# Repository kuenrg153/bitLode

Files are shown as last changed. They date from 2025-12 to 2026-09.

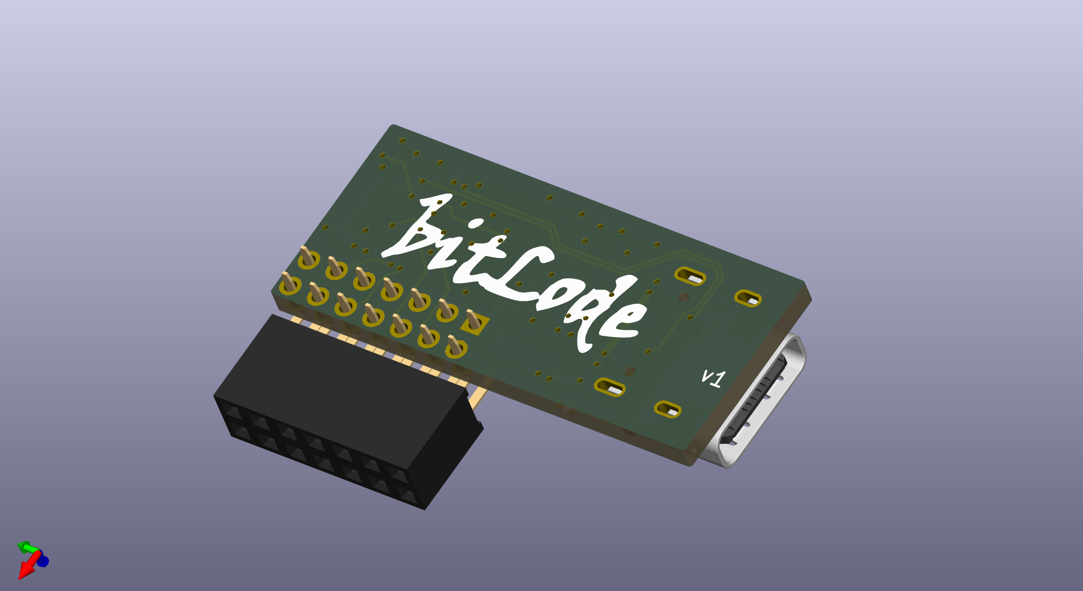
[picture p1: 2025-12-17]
doc/bitLodePCBA.png

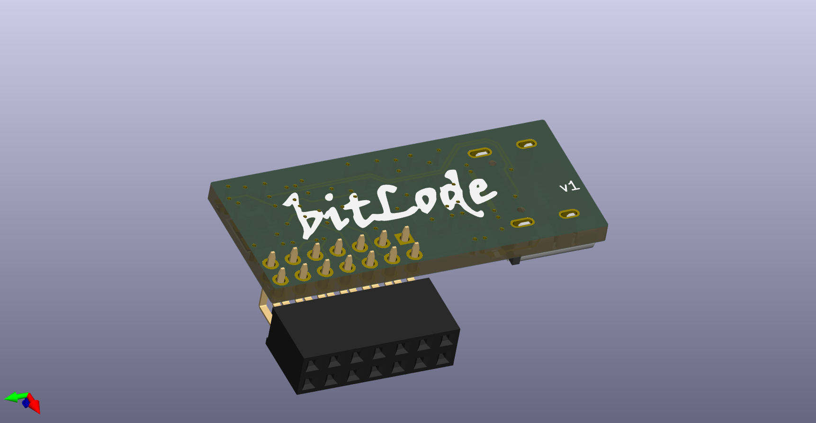
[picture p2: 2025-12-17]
bitLoadPCBA.png

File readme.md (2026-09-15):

## bitLode V2

bitLode

bitLode V2 is an RP2040 USB adapter that connects a PC, laptop or Raspberry Pi to a Whatsminer M30 (and similar)
hashboard. It exposes the hashboard's UART, reset and I2C over USB.

It's a fork of [aditBoard v2](https://github.com/skot/aditBoard/tree/v2) by Skot. It changes the
board for Whatsminer hashboards and adds firmware, host tools and an AI diagnostics skill.

| Path | Contents |
|---|---|
| `bitLodeV2.kicad_pro` / `.kicad_sch` / `.kicad_pcb` | KiCad 10 project: schematic and 6-layer PCB |
| `bitLodeV2.kicad_sym`, `bitLodeV2.pretty/`, `bitLodeV2.3dshapes/` | project-local symbols, footprints and 3D models |
| `Manufacturing Files/` | Gerbers, drill files, BOM and component placement for PCBA (e.g. [JLCPCB](https://jlcpcb.com)) |
| [`firmware/`](firmware/) | RP2040 firmware source (Rust/Embassy) with prebuilt `bin/bitlode-fw.elf` and `bin/bitlode-fw.uf2` |
| [`tools/`](tools/) | Python host tools: port discovery, system commands, hashboard init/replay, nonce verification, rig power |
| [`skills/`](skills/) | AI agent skill for diagnosing a Whatsminer M30S (KF1950) hashboard through the bitLode |

### Quick start

1. **Hardware** Send `Manufacturing Files/gerbers/`, the BOM and the placement file to your PCB assembler. Some notes: 

a) Fab houses might try to replace the cyrstal with an oscillator (learned this the hard way) - don't let them!

b) The LED is hard to source - but it works fine with out it!

c) Just do SMT at the fab house - solder the connector yourself and save a little bit. You can even try to sample the connector for free from Samtec - SQT-107-01-L-D-RA

d) Note that this version interferes with the fan in the original enclosure. If you're looking to use it long term in the enclosure you probably want to modify it (make the board into a bit of an upside down L and extend the header down) to clear the fan.

e) Currently I have NOT made the AntHat (https://github.com/skot/AntHat) equivalent for controlling the Whatsminer PSU and fans. Let me know if there is interest there.

bitLode_2sides

2. **Firmware** 
The firmware is based on https://github.com/256foundation/emberone-usbserial-fw with a few modifications around baud rates.

If you have trouble flashing it via the regular uf2 over boot loader then you can try using a Pi Pico running Debugprobe
https://www.electronics-lab.com/understanding-the-ways-to-debug-your-raspberry-pi-pico-development-board/

If you go this route then it's really handy to get an adapter ( https://www.aliexpress.com/item/1005009527726103.html ) to bring out the SWD lines.

To build it yourself, see [`firmware/README.md`](firmware/README.md).
   
3. **Plug in USB.** The board appears as `e3be:40e1` with two serial ports: control (interface 0) and ASIC UART (interface 2).
   ```sh
   pip install pyserial
   python3 tools/bitlode_sys.py ident   # -> ember-one kf1950 pio96 +sys-cmds 2026-09-15
   ```

### AI skill
The point of these skills is to help people learn how to communicate with, configure and diagnose Whatsminer M30 hashboards. 

I haven't yet done it but you could pair these skills up with Mujina (https://github.com/256foundation/mujina) and actually hash. Note that the RP2040 canNOT keep up with the 12Mbaud native baud rate required to fully hash but maybe someone can run with this project and figure that out.

`skills/bitlode-hashboard-diag/` is a [Claude Code skill](https://docs.claude.com/en/docs/claude-code/skills).
Link it into your skills directory, then run the agent from the repository root so its
relative paths (`tools/`, `sessions/`, `captures/`) resolve:

```sh
mkdir -p ~/.claude/skills
ln -s "$PWD/skills/bitlode-hashboard-diag" ~/.claude/skills/bitlode-hashboard-diag
```

Before its hashing test (T3), the skill needs:
- the job pool, generated once with `cd tools && python3 make_fresh_jobs.py 165000`
- the `whatsminer_private_api_py` package (its `wm_ssh.py`) for `tools/wm.sh`, pointed to by `WM_API_DIR`
- a known-good nonce capture for the verifier's control, pointed to by `KF_CONTROL_PKL`

### License

Firmware: GPL-3.0 (see `firmware/LICENSE`).

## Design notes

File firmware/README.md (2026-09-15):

# bitLode firmware

RP2040 firmware for the bitLode board. It turns one USB connection into two serial ports:
a **control port** (I2C, GPIO, ADC, LED, system commands) and a **data port** that passes
UART traffic straight through to the hashboard ASIC chain.

| | |
|---|---|
| USB VID:PID | `e3be:40e1` |
| Manufacturer / product | `256F` / `EmberOne00` |
| Serial number | murmur3 hash of the SPI flash's 64-bit unique ID (different on every board) |
| Identity string | `ember-one kf1950 pio96 +sys-cmds 2026-09-15` (control page `0x0F`, cmd `0x00`) |
| System clock | 96 MHz from the 12 MHz crystal, so the PIO UART divides exactly to 12 Mbaud |

Prebuilt images of this source are in [`bin/`](bin/): `bitlode-fw.elf` for SWD and `bitlode-fw.uf2` for the USB bootloader.

## Building

```sh
curl --proto '=https' --tlsv1.2 -sSf https://sh.rustup.rs | sh
rustup target add thumbv6m-none-eabi

cargo build --release --locked
# output: target/thumbv6m-none-eabi/release/firmware (ELF)
```

## Flashing

**SWD** (any debug probe, e.g. a Pico running Debugprobe, on SWCLK / SWDIO / GND):

```sh
openocd -f interface/cmsis-dap.cfg -f target/rp2040.cfg -c "adapter speed 1000" \
        -c "program bin/bitlode-fw.elf verify reset exit"
# or: cargo install probe-rs-tools --locked && cargo flash --release --chip RP2040
```

**USB bootloader.** If the board already runs this firmware, reboot it into the RP2040 ROM
bootloader with `tools/bitlode_sys.py bootsel`. On a blank board, hold BOOTSEL while plugging in USB.
Then copy `bin/bitlode-fw.uf2` onto the `RPI-RP2` drive.

## Pinout

| RP2040 pin | Function |
|---|---|
| GPIO8 / GPIO9 | ASIC UART TX / RX (PIO UART) |
| GPIO11 | `asic_resetn` (active low, idles high) |
| GPIO0 | `asic_pwr_en` (active high, idles low) |
| GPIO18 | `asic_io_pwr_en` (active high, idles low) |
| GPIO14 / GPIO15 | I2C SDA / SCL |
| GPIO26 / GPIO27 | ADC VDD / VIN |
| GPIO1 | RGB status LED (WS2812) |

## Data port (USB interface 2)

- Every byte is passed through in both directions.
- The host's baud rate is applied to the ASIC UART, including the rate set when the port is first opened.

## Control port (USB interface 0)

The baud rate doesn't matter.

**Request**

| 0 | 1 | 2 | 3 | 4 | 5 | 6… |
|---|---|---|---|---|---|---|
| LEN LO | LEN HI | ID | BUS | PAGE | CMD | DATA |

- `LEN` is the total packet length in bytes, including itself.
- `ID` is any byte; the reply echoes it.
- `BUS` is always `0x00`.

**Reply**

- **Success:** `u16 LE data length`, `ID`, `data`.
- **Error:** `u16 LE total length`, `ID`, `code`, optionally followed by an ASCII message. The codes are `0x10` timeout, `0x11` invalid command, `0x12` buffer overflow and `0xFF` message. An error reply is shorter than its length field says.

### I2C, page `0x05`

| Cmd | Data | Action |
|---|---|---|
| `0x10` | u32 LE Hz | set bus frequency |
| `0x20` | addr, bytes… | write |
| `0x30` | addr, n | read n bytes |
| `0x40` | addr, bytes…, n | write then read n bytes |

Example, reading one byte from `0x4C`: `08 00 01 00 05 30 4C 01`

### GPIO, page `0x06`

Commands are `0x00` for `asic_resetn`, `0x01` for `asic_pwr_en` and `0x02` for `asic_io_pwr_en`. To set a pin, send one data byte (`0` = low, `1` = high). To read its level, send no data.

Examples:
- Release ASIC reset: `07 00 00 00 06 00 01`
- Read ASIC reset: `06 00 00 00 06 00`

### ADC, page `0x07`

`0x50` reads VDD and `0x51` reads VIN. The reply is a raw u16 LE (12 bit).

### LED, page `0x08`

`0x10 R G B` sets the colour. Example, magenta: `09 00 00 00 08 10 FF 00 FF`

### System, page `0x0F`

| Cmd | Reply |
|---|---|
| `0x00` | firmware identity string |
| `0x01 B0 07` | ack `01`, then the board reboots into the RP2040 USB bootloader. The 2-byte key stops a garbled packet from triggering it. |

## License

GPL-3.0. See [LICENSE](LICENSE). Based on the Ember One usbserial firmware by the 256 Foundation.

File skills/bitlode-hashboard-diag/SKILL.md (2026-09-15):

---
name: bitlode-hashboard-diag
description: Diagnose a Whatsminer M30S (111 × KF1950) hashboard driven by a bitLode V2 (RP2040, USB e3be:40e1). Covers pre-flight, powering and holding the shared WM rail, board identity, I2C temp, hashboard EEPROM dump/decode/repair, a per-ASIC comms/register census, a full SHA256d-verified per-chip hashing test, frequency/thermal margin, symptom-to-cause tables and the harness traps that produce false results. Use for any bitLode + hashboard health check, bad-chip hunt or EEPROM work.
---

# bitLode × WM hashboard — diagnostics

The **bitLode V2** (RP2040, firmware in `firmware/` of this repo) drives a Whatsminer
M30S VE2x hashboard (111 × KF1950 in 37 × 3 series-parallel) over **TXD / RXD / RST + I2C**. The
WM control board stays in the loop **only as the PSU**: the hashboard rail is the WM's
`/sys/bitmicro/power` output.

Paths below are relative to the root of this repository. Protocol claims not marked as measured
on the wire or verified by SHA are hypotheses.

## 0. Ground rules (non-negotiable)

1. **Ask the user before energising the hashboard**, every session. They manage power manually to avoid overheating. Power the rig only for the run, and turn it off as soon as the run ends.
2. **Power-off is the FIRST statement of any abort path.** Only `kill` a PID that is set and > 1: `kill 0` kills the runner before `off` runs, and the rig stays on.
3. **Never run `rigpower.py state` as a check. It POWERS THE RIG OFF**, because opening `/dev/ttyUSB0` resets the Arduino. To check power, ask the chain instead: chip-ID broadcast, or WM sysfs.
4. **EEPROM writes need the user's explicit approval of the exact bytes**, plus a verified backup. `bitlode.py` enforces the backup and a dry run. Never write the WM's own config over SSH without approval.
5. Write every run into `sessions/<name>_<YYYYMMDD>/` with a README (asked / ran / came back). Run `python -u`, with bounded drains, a `write_timeout` on serial ports, and a `timeout` wrapper around everything.

## 1. Rig map (verify each session; things move)

| Item | Typical value | How to confirm |
|---|---|---|
| bitLode ctrl / data | USB interface 00 / 02 of `e3be:40e1` (e.g. `/dev/ttyACM0` / `/dev/ttyACM1`) | `bitlode.py find`. With several bitLodes attached, set `BITLODE_CTRL` / `BITLODE_DATA` |
| bitLode serial | unique per board (hash of the flash unique ID) | `bitlode.py find` |
| Firmware | `ember-one kf1950 pio96 +sys-cmds 2026-09-15` | `bitlode.py ident` |
| Rig power | Arduino `/dev/ttyUSB0`, **SSR on GPIO8: `8H` = ON, `8L` = OFF** | `tools/rigpower.py on\|off` only |
| WM control board | DHCP address on the rig LAN (it moves; `wm_ssh.py` hardcodes the IP) | `ping`; API `{"cmd":"summary"}` on :4028 |
| WM shell | SSH is off after every boot. Enable it with `enable_ssh_verbose.py <IP>` from whatsminer_private_api_py, then `tools/wm.sh '<cmd>'` (set `WM_API_DIR`) | `wm.sh 'echo ok'` |
| Rail sysfs | `/sys/bitmicro/power/{enable,vout_set(cV),vout,iout(mA),common_status}` | |
| Logic analyser (DSLogic) | Ch0 RXD · Ch1 RST · Ch2 TXD · Ch3 RST_DET (3.3 V) · Ch4-7 ASIC0/1 RXD·TXD·CTSI·RST (1.8 V) · **vth 0.9 V** | buffer mode silently REPEATS past depth |
| Python | python3 with pyserial (+ paramiko for `wm.sh`) | |

**Shared PSU:** with the WM rail off, the hashboard is dead even though the bitLode enumerates
fine on USB. A 0-chip result means nothing until you've confirmed the rail was on.

## 2. Pre-flight (hashboard unpowered, nothing risky)

```bash
S=skills/bitlode-hashboard-diag/scripts; PY=python3
lsusb | grep -E 'e3be:40e1|1a86:7523|2a0e:0034'   # bitLode, Arduino, DSLogic
$PY $S/bitlode.py find
$PY $S/bitlode.py ident      # want: "ember-one kf1950 pio96 +sys-cmds 2026-09-15"
$PY $S/bitlode.py rst get    # 1 = released (idle HIGH)
```
- A **wedged bitLode** (data port silent, ctrl port times out) needs a USB replug. Cutting VBUS does not clear it.
- **Wrong VID:PID or no SYSTEM page reply** means the board isn't running this firmware. Flash `firmware/bin/bitlode-fw.elf` over SWD (see `firmware/README.md`). On a board already running it, use `tools/bitlode_sys.py bootsel` and copy `firmware/bin/bitlode-fw.uf2` to RPI-RP2.
- Close every other holder of the bitLode ports first (`fuser /dev/ttyACM*`). Control commands collide with a running replay.

## 3. Power up and HOLD the rail (the #1 source of false "dead board")

btminer on the WM cycles and **drops the shared rail whenever it exits**. A bitLode enumeration
that lands in a rail-off window returns **0 chips**. Sequence:

1. With the user's OK: `python3 tools/rigpower.py on`, then wait for ping. **Wait until WM uptime is ≥ 180 s**; a lockdown applied earlier gets undone by the boot sequence.
2. Enable SSH (above).
3. Lockdown, all in one `wm.sh` call:
   ```sh
   mv /tmp/miner-state.log /tmp/miner-state.log.held   # keepalive.sh only respawns daemons if this exists
   /etc/init.d/system-monitor stop; /etc/init.d/btminer stop; killall btminer; sleep 2
   ini set /tmp/fan_runtime.cfg Config speed_auto_adjust 0
   echo 100 > /sys/bitmicro/fan/pwm_duty; echo 100 > /sys/class/fanspeed/pwm_duty   # fan auto mode only sees the WM board
   echo 1 > /sys/bitmicro/power/enable; echo 1181 > /sys/bitmicro/power/vout_set   # PIN the voltage; never inherit it
   ```
4. Gate numerically before any chain work: `en=1`, `common_status=0x0`, `vout` within ±25 cV of the set point, no btminer or system-monitor PID, and fan tach `speed0/1` ≥ 200.
5. Log the rail every 1–5 s for the whole run, and abort (power off first) if `en=0`, `iout > 75 A`, board temp ≥ 70 °C, or btminer or system-monitor comes back.

⚠ **Known open problem (2026-09-15):** some unidentified launcher still restarts btminer and drops `en` within about 45 s, and repeated lockdowns failed in that session. If the rail won't hold, stop and tell the user. **Do not toggle `enable` in a loop.** Repeated toggling can latch a PSU fault (`enable=1`, `vout=0`, `common_status≠0`) that only a **full AC cycle at the relay** clears.

Voltage: 1181 cV ≈ 0.318 V/chip (strings of 37). Bring-up needs **≳ 0.30 V/chip**. Initialising below about 0.27 V "succeeds" but leaves a board that echoes jobs and never hashes. Once a good init is done, hashing is fine down to 0.259 V.

## 4. Test ladder

Run in order and stop at the first failure. Each tier's pass is only meaningful if the tier before it passed.

### T1: Board identity (I2C: EEPROM + temperature sensor)
```bash
$PY $S/bitlode.py i2c-scan        # expect 0x48 (temp) + one EEPROM in 0x50-0x57
$PY $S/bitlode.py temp            # idle ~30 °C; hashing guard 70 °C
$PY $S/bitlode.py eeprom-dump     # 3 identical reads, auto-saved to captures/, decoded
```
If the I2C bus is silent unpowered, retry with the rail held, since the connector's 3.3 V may come from the board. The I2C bus never reaches the ASICs, so **EEPROM content cannot affect hashing under the bitLode**. It only configures a WM controller. See §5.

### T2: Per-ASIC comms and register census (no work, ~30 s, 198 MHz)
```bash
$PY -u $S/chain_census.py --freq 198 --reps 3 --json <session>/census.json
```
The tool resets the chain (1 s), enumerates at 375000, sends burst0/burst1, follows the switch to 2 Mbaud, writes
the per-chip nonce-base sweep + a PLL frame + a ticket mask, and reads back per chip: `0x100` chip ID,
`0x800` own nonce base (per-chip write path), `0x031` PLL, `0x051` mask, `0x24A` die temp, and `0x236`
PVT monitor. It leaves the mask parked.

| Result | Meaning |
|---|---|
| 111 enum, 111 @2M, no flags | Comms and config are good on every chip. Go to T3. |
| enum = N < 111 | Chips 0..N-1 are reachable; **chip N or the link into it** is at fault (dead die, cracked joint, a failed string/LDO) |
| 0 enum | Rail not held · bitLode wedged · board killed by over-frequency (**rail power-cycle**; soft reset returns 0) · power-up baud ≈170 k |
| enum 111 but fewer @2M | Marginal fast link, or the chain was left half-dead by a previous arm (**rail cycle**, not reset) |
| one chip silent/intermittent mid-chain, others beyond it answer | That chip's addressing/logic; the link passes through it fine |
| `W` wrong value | Per-chip write didn't land (addressing or corruption) |
| `P` wrong on all | Reading a STALE PLL: link was saturated or the write never landed. Readback must match what you *intended* this run. |
| `T`/`S` outlier, `S` = 1023 | Thermal hot spot / poor heatsink contact · saturated or bad PVT monitor. Die temp is a board profile (hottest ~40 % along), not a gradient |

⚠ Census verifies comms and register state only. **It cannot prove the cores hash**: a dead
24 MHz crystal answers UART normally and never hashes. That's what T3 is for.

### T3: Full function test: SHA256d-verified hashing, attributed per chip
Use the best-proven configuration (paced, fresh work, jobs advancing, 400 MHz fixed, n=2, 380 j/s).
It ran at 2.56 TH/s on a healthy board (2026-09-10 job-rate sweep). `KF_RESTORE_CE=1` adds about 7 % on its own, but it has never been combined with `KF_CE_FULL`.
```bash
cd tools
env KF_JOBS=fresh KF_REPEAT_BATCH=0 KF_CE_FULL=1 \
    KF_PLL_MODE=fixed KF_FREQ=400 KF_TICKET_N=2 \
    KF_N_X81=694 KF_N_LEG=320 KF_PACE_HZ=379.8 KF_RUN_S=150 KF_TAG=diag_<board> \
    timeout 400 $PY -u kf1950_rearm_replay.py | tee <session>/diag.log
#   ~33 s job-pool load, 1 s reset, 15 s wait, gates: >=100 chips enum AND >=100 @2M
#   RX -> sessions/rx_diag_<board>.bin (flushed live; override with KF_OUT_DIR)
$PY verify_nonces.py ../sessions/rx_diag_<board>.bin \
    --jobs jobpool/fresh_x81.bin --per-chip <session>/perchip.json
$PY $S/perchip_flag.py <session>/perchip.json
```
**Pass criteria (healthy reference):**
- Verifier **CONTROL PASS** (mandatory; if it fails, interpret nothing). The control needs a capture of two known-good stock-controller nonces (`x81b.pkl`); point `KF_CONTROL_PKL` at it.
- ≥ 97 % of distinct nonce events verify at ≥ 34 bits; deepest tail reaches 40+.
- Hashrate = verified/s × 2^(32+n) ≈ **2.4–2.6 TH/s** at 400 MHz, n=2, 380 j/s. This is a bitLode-drive figure, not the board rating (29–30 TH/s under the stock controller at ~668 MHz).
- `perchip_flag.py` PASS: every chip within 5σ of the board mean, and observed sd ≈ Poisson (a healthy run gives sd 10.3 vs √mean 11.0). Chips 0 and 110 hash normally.
- The post-run liveness block still reads 111 chips (`reg 0x100`, `0x051`, `0x24A`).

**Interpreting failures:**
- **Gate FATAL**: go back to T2.
- **Echoes (`byte9 ≥ 0xC0`) but 0 nonce candidates**: frequency or PLL frame, mask never unparked, or a bad init voltage.
- **Candidates but 0 verified**: almost always the **wrong `--jobs` pool**. Run the verifier against the pool the run actually sent.
- **A DEAD or WEAK chip in `perchip_flag`** while it passed T2: that chip's cores or clock are bad (comms fine, hashing not). Confirm by repeating. `KF_SOLO=<hex>` makes one chip hash alone, but the rest of the chain still clocks and draws power. ⚠ SOLO was running when a board went 111→1 on 2026-09-11, so use it briefly.
- **Board-wide low rate with a uniform spread**: voltage, temperature, job delivery (blob writes cost 100×; check `KF_PACE_HZ` is set), or baud.

### T4: Margin and stress (optional; ask first; can kill the chain)
- **Frequency ceiling:** `KF_PLL_MODE=ramp KF_FREQ_TARGET=<MHz>` (+6 MHz per 2.67 s cycle). **Never jump**: a jump to 618 kills the chain, while a ramp to it is fine. The reference board was productive to about 720 MHz and silent by 768. You can tell the chain has died when `reg 0x031` returns 0 B. **Recovery is a rail power-cycle only.**
- **Thermal soak:** at hashing load (~50 A rail) watch the `0x48` temp and `iout`. Healthy ΔI per chip over baseline is about **6 A at init/198 MHz, rising ≈3.4 A per 100 MHz** (18 A at 564). A die drawing a flat, frequency-independent current points to leakage or damage.
- A run that goes silent progressively (RX lost at 96 s, then 56 s, then no enumeration) is **cumulative heating**: fans at idle, or voltage pinned too high. Cool it and re-test before calling the silicon bad.

## 5. Hashboard EEPROM

**Part:** 24C01 (128 B) or 24C02 (256 B). Both have been seen; `eeprom-dump` detects which by the
128-B wrap. Address `0x50` through the bitLode connector. On the WM control board the slot-N
view is `/sys/devices/platform/soc/twi0/i2c-0/0-005N/eeprom` (slot 2 = `0-0052`). Scan before assuming an address.

**Layout (known-good):**
```
0x00  data_tag  fa = valid, 00 = administratively disabled (btminer asserts), ff = blank
0x01  magic 5a
0x02  pcb_len 0x14(20)   0x03  chip_len 0x1e(30)   0x04  ts_len 0x13(19)
0x05  pcb_data   "AEM1ES6F211C10X10422"
0x19  chip_data  "H3AP04-21111103 BINV03-195004D"  -> bin_version 03, chip 1950, bin_type 04, leak D
0x37  timestamp  "2021-12-14 12:30:43"          record ends exactly at 0x4a
0x77-78  ff ff (no CRC on good boards)
0x7c-7d  rated hashrate LE16 GH/s (e.g. 0x752b = 29995)
```
No checksum. What the WM checks is `tag == fa 5a` plus declared lengths that exactly match the content.

**Procedure:**
1. `eeprom-dump` (3 identical reads, saved) and **copy the file somewhere durable** before anything else.
2. `eeprom-decode FILE` shows `[BAD]` for tag, length/overrun, or non-ASCII bytes.
3. Build the fix **from the board's own values**. Never invent serials or bins. Then dry-run:
   `bitlode.py eeprom-write --offset 0x03 --hex 1e`. It prints old→new per byte and writes nothing.
4. Show the user the exact byte plan and get approval. Then add `--yes`. The tool re-backs-up to `captures/eeprom_0x50_prewrite_*.bin`, writes byte-wise (12 ms each), re-reads 3×, verifies all bytes and re-decodes. A verify failure usually means WP is tied high or it's the wrong part.
5. Revert: `bitlode.py eeprom-restore <backup.bin> --yes` (writes only the differing bytes).
6. Log it in `captures/EEPROM_CHANGELOG_<SN>.md` (before/after bytes, md5, revert command).

**Status:** bitLode I2C *reads* of the EEPROM are proven (2026-07-29). The bitLode *write* path follows the
firmware source (`0x20 addr offset byte`) and standard 24Cxx practice, but **has not yet been run on this rig**.
Treat its first use as a test: a one-byte, easily reverted change, verified afterwards. The WM-side path is proven:
`printf '\x1e' | dd of=/sys/.../0-0052/eeprom bs=1 seek=3 count=1 conv=notrunc`.

**Learned the hard way:**
- `write-eeprom-data -s N -d/-c` on the WM **silently skips the string fields**. It writes only the hashrate plus a CRC at 0x77/0x78, which then have to be restored to `ff ff`. Use `dd` for strings and the tag.
- **A record that parses is not a correct record.** A one-byte length fix made the 09-08 board parse as `M30S_V21`, 156 chips, 4 columns, leak A. All plausible, all wrong. Cross-check the derived chip count (111) and column count (3) against the hardware.
- EEPROM faults show up as **PSU errors** on the WM (`No power matched! need power: P221C, vender: 1`, `ErrorCode[422] parser eeprom error`). Five PSU hypotheses were falsified before the EEPROM was found to be the cause.
- Corruption seen: `0x14` where `A`/`0` belong, `0x29` where `V`/`2` belong, a missing space before `BIN`, and length byte `0x53` instead of `0x1e`. It was a different programming tool, not an encoding.

## 6. Symptom → first suspect

| Symptom | First suspect → check |
|---|---|
| 0 chips, adapter enumerates | Rail off (btminer cycling) → WM sysfs `en/vout`; then replug the bitLode |
| 0 chips at every baud, alternating with power cycles | Relay-op parity / Arduino DTR reset → one relay op per cycle (`run_retry.sh` pattern) |
| 1 chip, reply CRC-valid | Chip 0 and its link are fine; the chain beyond chip 0 is dead. Stress history? A rail cycle doesn't fix it ⇒ board damage |
| Chain answers no register reads after a ramp | Over-frequency death → rail power-cycle; cap the frequency below the board's ceiling |
| 111 enum, ~half answer at 2M | Degraded by the previous arm → rail cycle |
| Replay hangs, no log lines | Dead chain + `write_timeout=None` → always set `write_timeout` |
| "Hashes" but the nonce count is identical across different arms | **Censored metric** (`KF_REPEAT_BATCH=1` exhausts a fixed job set) |
| 0 verified on a good-looking run | Verifier `--jobs` doesn't match `KF_JOBS` |
| Static DSLogic line during known traffic | Upper-chip common mode 23–25 V → probe at ASIC 0/1; or `vth` wrong; or a floating channel chattering |
| `pgrep -f` wait loop never ends | The pattern matches itself → use `name[x]` or a PID |
| Temp OK on WM, bitLode board cooking | Fan auto mode only sees the WM board → force the fans, guard on `0x48` |

## 7. Protocol quick reference (for ad-hoc probes)

- Frame: `FF FF [reg>>4] [((reg&0xF)<<4)|4] [len] [data] [CRC8]`. READ = low nibble 0, 6 B: `FF FF [b2] [b3] [resp_len] [CRC]`.
- CRC-8: poly 0x31, init 0xFF, no reflection, covering all bytes including `FF FF`. No exceptions.
- Replies are addr-FIRST: `[addr] 00 00 [len] [data] [CRC]`. Never parse by `bytes // size`; scan for CRC-valid records.
- Chip ID `FF FF 10 00 06 D5` → pre-address reply `FF FF 00 06 19 50 00 00 00 00 F4` per chip, at **375000** baud (not 363636).
- After burst1 the chain is at **2 Mbaud** (this WM's config; factory is 12 M) and the host **must follow**. bitLode USB is full-speed, so link capacity plateaus around 550 KB/s (6 M is the useful ceiling).
- PLL frequency: `03 14 06 [fbHi fbLo] 04 [pd] 03 AA`, with pd = 2 below 300 MHz, 1 below 600, 0 otherwise, and fb = round(2^pd·f/6). The `04 05 [domain]` form is NOT a frequency write.
- Ticket mask `reg 0x051`: n=32 parks (no reports, echoes included); threshold = 32+n bits.
- `04 06` 11-B frames are mostly job **echoes** (byte9 ≥ 0xC0). Real nonces can only be told apart by SHA256d.
- Control port: `u16 total_len, id, 0, page, cmd`. Pages: 5 = I2C (`10` freq, `20` write, `30` read, `40` write-read), 6 = GPIO (`00` RESETN; `01` PWR_EN does nothing on M30S), 7 = ADC (not characterised here), 0x0F = SYSTEM (`00` ident, `01 B0 07` BOOTSEL). An error reply is shorter than its length field (codes 0x10/0x11/0x12/0xFF+msg).

## 8. Files

| Path | Use |
|---|---|
| `scripts/bitlode.py` | ports, ident, RESETN, ADC, temp, I2C scan, EEPROM dump/decode/write/restore |
| `scripts/chain_census.py` | T2 per-ASIC comms and register census (no power switching) |
| `scripts/perchip_flag.py` | T3 dead/weak chip detection from `verify_nonces.py --per-chip` JSON |
| `tools/kf1950_rearm_replay.py` | the hashing driver; every `KF_*` knob is documented in its header |
| `tools/verify_nonces.py` | SHA256d verifier with a mandatory control; `--per-chip`, `--shuffle` (derangement; use a ~1k-event file) |
| `tools/rigpower.py`, `wm.sh`, `bitlode_board_temp.py`, `bitlode_sys.py` | power, WM shell, temp, firmware |
| `tools/make_fresh_jobs.py` | builds `tools/jobpool/fresh_x81.bin` from `x81_jobs.bin` (run `make_fresh_jobs.py 165000` once before T3) |
| `captures/eeprom_*.bin`, `EEPROM_CHANGELOG_*.md` | EEPROM backups written by `bitlode.py` (git-ignored) |

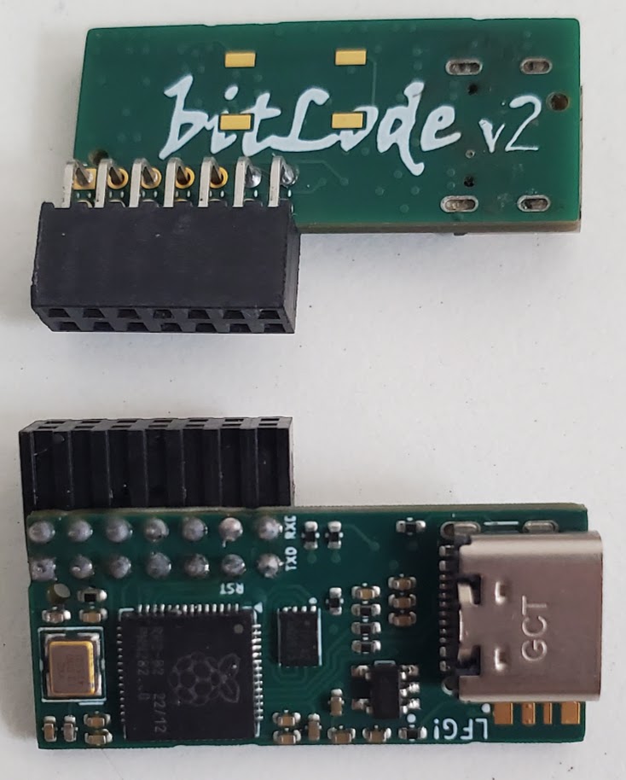
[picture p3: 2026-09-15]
artwork/bitLode_2sides.jpg

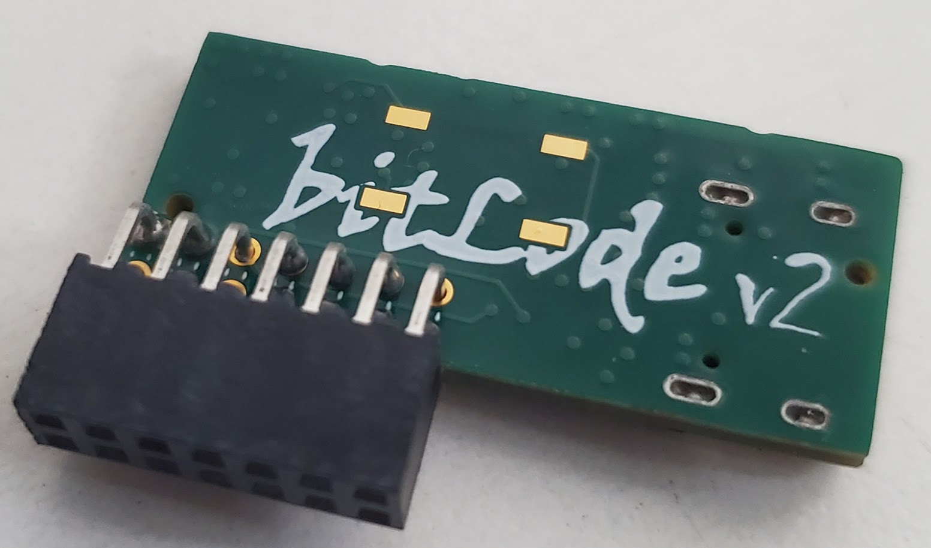
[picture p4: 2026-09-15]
artwork/bitLode.jpg

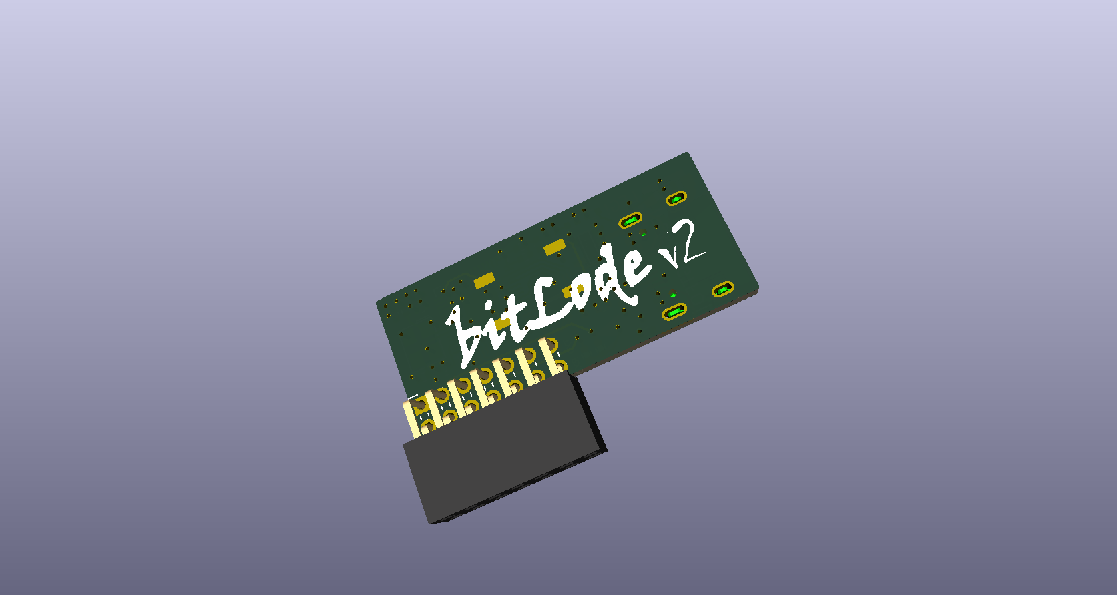
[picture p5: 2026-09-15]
artwork/bitLodeV2.png

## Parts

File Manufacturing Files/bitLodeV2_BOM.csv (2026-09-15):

Id | Designator | Footprint | Quantity | Designation | Supplier and ref
1 | C2, C4 | C_0402_1005Metric | 2 | 30pF
2 | C5, C6, C7, C10, C11, C12, C13, C14, C15, C16 | C_0402_1005Metric | 10 | 0.1uF
3 | C8, C9, C17, C18 | C_0402_1005Metric | 4 | 1uF
4 | J1 | USB_C_Receptacle_GCT_USB4105-xx-A_16P_TopMnt_Horizontal | 1 | USB_C_Receptacle_USB2.0
5 | J2 | PinSocket_2x07_P2.00mm_Horizontal | 1 | Conn_02x07_Odd_Even
6 | R1 | R_0402_1005Metric | 1 | 10k
7 | R2, R3 | R_0402_1005Metric | 2 | 33
8 | R4, R5 | R_0402_1005Metric | 2 | 5.1k
9 | R6 | R_0402_1005Metric | 1 | 1k
10 | R7 | R_0402_1005Metric | 1 | 49.9k
11 | R25, R27 | R_0402_1005Metric | 2 | 4.7K
12 | U1 | LED-SMD_4P-L4.0-W1.6-L | 1 | SK6812
13 | U2 | USON8_L2.0-W3.0-P0.50-BL-EP | 1 | W25Q16JVUXIQ
14 | U3 | QFN-56-1EP_7x7mm_P0.4mm_EP3.2x3.2mm | 1 | RP2040
15 | U4 | SOT-25-5_L2.9-W1.6-P0.95-LS2.8-BL | 1 | AP2112K-3.3TRG1
16 | Y1 | OSC-SMD_4P-L3.2-W2.5-BL | 1 | 12MHz

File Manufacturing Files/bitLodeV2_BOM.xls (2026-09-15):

Comment | Designator | Footprint
0.1uF | C13,C11,C7,C10,C14,C6,C12,C5,C16,C15 | 0402
AP2112K-3.3TRG1 | U4 | SOT-25-5_L2.9-W1.6-P0.95-LS2.8-BL
10k | R1 | 0402
30pF | C2,C4 | 0402
W25Q16JVUXIQ | U2 | USON8_L2.0-W3.0-P0.50-BL-EP
Conn_02x07_Odd_Even | J2 | PinSocket_2x07_P2.00mm_Horizontal
1uF | C18,C17,C9,C8 | 0402
RP2040 | U3 | QFN-56-1EP_7x7mm_P0.4mm_EP3.2x3.2mm
12MHz | Y1 | OSC-SMD_4P-L3.2-W2.5-BL
5.1k | R4,R5 | 0402
33 | R3,R2 | 0402
4.7K | R27,R25 | 0402
USB_C_Receptacle_USB2.0 | J1 | USB4105
1k | R6 | 0402
49.9k | R7 | 0402
SK6812 | U1 | LED-SMD_4P-L4.0-W1.6-L

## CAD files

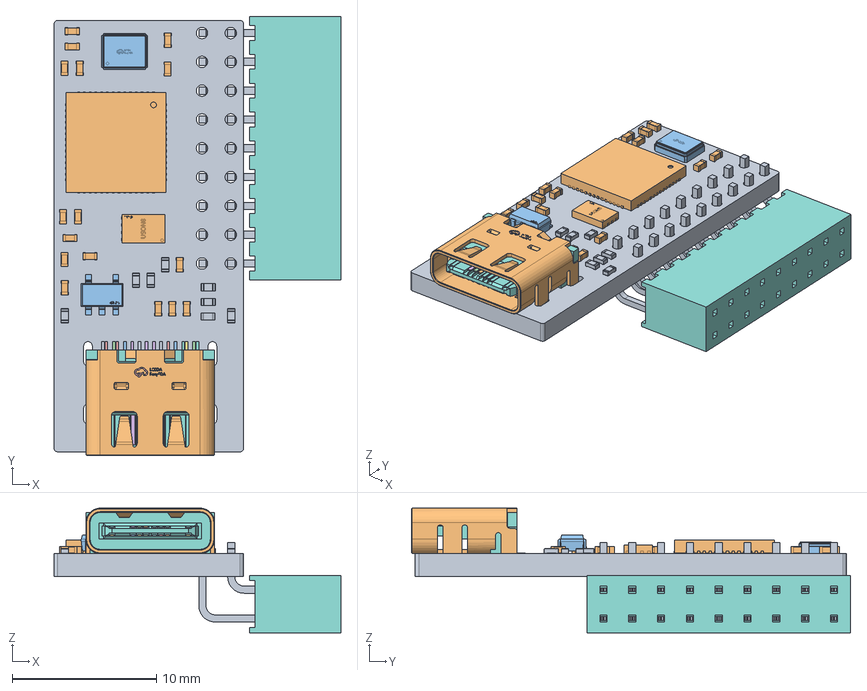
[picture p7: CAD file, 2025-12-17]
CAD/bitLode.FCStd
19.9 x 30.5 x 8.66 mm
Pcb_7cad
C13_C_0402_1005Metric_86b2b0d83743 x 16
SOT-25-5_L2.9-W1.6-P0.95-LS2.8-BL
SOT-25-5_L2.9-W1.6-P0.95-LS2.8-BL001
SOT-25-5_L2.9-W1.6-P0.95-LS2.8-BL002
SOT-25-5_L2.9-W1.6-P0.95-LS2.8-BL003
SOT-25-5_L2.9-W1.6-P0.95-LS2.8-BL004
SOT-25-5_L2.9-W1.6-P0.95-LS2.8-BL005
SOT-25-5_L2.9-W1.6-P0.95-LS2.8-BL006
SOT-25-5_L2.9-W1.6-P0.95-LS2.8-BL007
SOT-25-5_L2.9-W1.6-P0.95-LS2.8-BL008
SOT-25-5_L2.9-W1.6-P0.95-LS2.8-BL009
SOT-25-5_L2.9-W1.6-P0.95-LS2.8-BL010
SOT-25-5_L2.9-W1.6-P0.95-LS2.8-BL011
SOT-25-5_L2.9-W1.6-P0.95-LS2.8-BL012
SOT-25-5_L2.9-W1.6-P0.95-LS2.8-BL013
R1_R_0402_1005Metric_9596e12d832e x 8
USON-8_L3.0-W2.0-H0.6-P0.50
USON-8_L3.0-W2.0-H0.6-P0.051
USON-8_L3.0-W2.0-H0.6-P0.052
USON-8_L3.0-W2.0-H0.6-P0.053
USON-8_L3.0-W2.0-H0.6-P0.054
USON-8_L3.0-W2.0-H0.6-P0.055
USON-8_L3.0-W2.0-H0.6-P0.056
USON-8_L3.0-W2.0-H0.6-P0.057
USON-8_L3.0-W2.0-H0.6-P0.058
USON-8_L3.0-W2.0-H0.6-P0.059
USON-8_L3.0-W2.0-H0.6-P0.060
USON-8_L3.0-W2.0-H0.6-P0.061
USON-8_L3.0-W2.0-H0.6-P0.062
USON-8_L3.0-W2.0-H0.6-P0.063
S1SQT-109-01-F-D-RA
P1SQT-109-01-F-D-RA
U3_QFN_56_1EP_7x7mm_P04mm_EP32x32mm_8852ba01f3ce
Y1_OSC-SMD_4P-L3.2-W2.5-CJ13-320001210A20_e5036b885edc
USB-C-SMD_G-SWITCH_GT-USB-7010ASV
USB-C-SMD_G-SWITCH_GT-USB-7010ASV001
USB-C-SMD_G-SWITCH_GT-USB-7010ASV002
USB-C-SMD_G-SWITCH_GT-USB-7010ASV003
USB-C-SMD_G-SWITCH_GT-USB-7010ASV004
USB-C-SMD_G-SWITCH_GT-USB-7010ASV005
USB-C-SMD_G-SWITCH_GT-USB-7010ASV006
USB-C-SMD_G-SWITCH_GT-USB-7010ASV007
USB-C-SMD_G-SWITCH_GT-USB-7010ASV008
USB-C-SMD_G-SWITCH_GT-USB-7010ASV009
USB-C-SMD_G-SWITCH_GT-USB-7010ASV010
USB-C-SMD_G-SWITCH_GT-USB-7010ASV011
USB-C-SMD_G-SWITCH_GT-USB-7010ASV012
USB-C-SMD_G-SWITCH_GT-USB-7010ASV013
USB-C-SMD_G-SWITCH_GT-USB-7010ASV014
USB-C-SMD_G-SWITCH_GT-USB-7010ASV015
USB-C-SMD_G-SWITCH_GT-USB-7010ASV016
USB-C-SMD_G-SWITCH_GT-USB-7010ASV017
USB-C-SMD_G-SWITCH_GT-USB-7010ASV018
USB-C-SMD_G-SWITCH_GT-USB-7010ASV019
USB-C-SMD_G-SWITCH_GT-USB-7010ASV020
USB-C-SMD_G-SWITCH_GT-USB-7010ASV021
USB-C-SMD_G-SWITCH_GT-USB-7010ASV022
USB-C-SMD_G-SWITCH_GT-USB-7010ASV023
USB-C-SMD_G-SWITCH_GT-USB-7010ASV024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

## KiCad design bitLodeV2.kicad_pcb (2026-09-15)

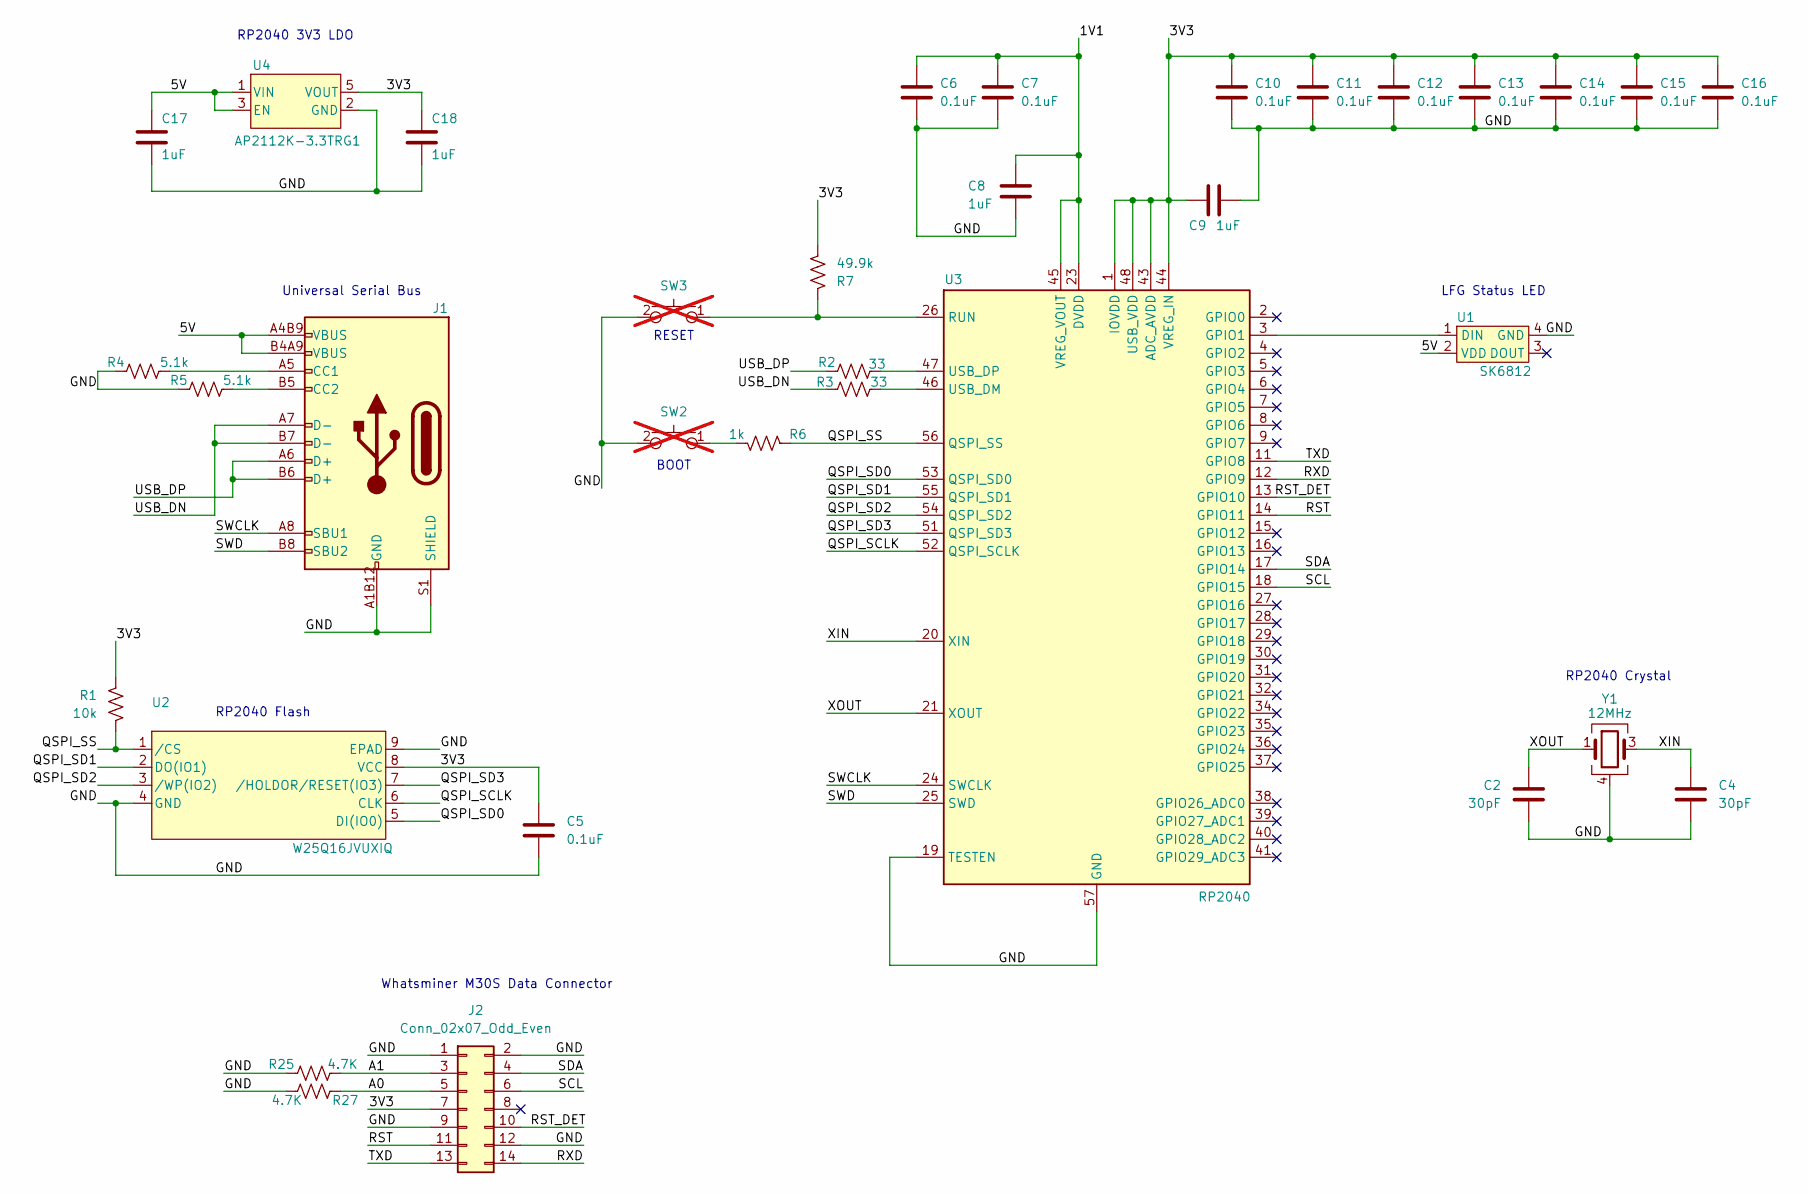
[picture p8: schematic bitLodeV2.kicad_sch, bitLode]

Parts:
C2, C4: 30pF; C_0402_1005Metric; PARTNO 0402CG300J500NT; JLC Part Basic Part
C5, C6, C7, C10, C11, C12, C13, C14, C15, C16: 0.1uF; C_0402_1005Metric; PARTNO CL05B104KB54PNC; JLC Part Basic Part
C8, C9: 1uF; C_0402_1005Metric; PARTNO CL05A105KA5NQNC; JLC Part Basic Part
C17, C18: 1uF; C_0402_1005Metric; PARTNO CL05A105KA5NQNC; LCSC C52923
J1: USB_C_Receptacle_USB2.0; USB_C_Receptacle_GCT_USB4105-xx-A_16P_TopMnt_Horizontal; PARTNO USB4105-GF-A; LCSC C2988369
J2: Conn_02x07_Odd_Even; PinSocket_2x07_P2.00mm_Horizontal
R1: 10k; R_0402_1005Metric; PARTNO 0402WGF1002TCE; LCSC C25744
R2, R3: 33; R_0402_1005Metric; PARTNO 0402WGF330JTCE; JLC Part Basic Part
R4, R5: 5.1k; R_0402_1005Metric; PARTNO RMCF0402JT5K10; LCSC C25905
R6: 1k; R_0402_1005Metric; PARTNO RC0402FR-071KL; LCSC C106235
R7: 49.9k; R_0402_1005Metric; PARTNO RC0402FR-0749K9L; LCSC C137969
R25, R27: 4.7K; R_0402_1005Metric; PARTNO RC0805FR-074K7L; LCSC Part C25900
SW2, SW3: GT-TC029B-H025-L1N; SW_CS1213AGF260_CRS; PARTNO CS1213AGF260; LCSC C5578986; not fitted
U1: SK6812; LED-SMD_4P-L4.0-W1.6-L; PARTNO SK6812SIDE-A-RVS; LCSC C2890037
U2: W25Q16JVUXIQ; USON8_L2.0-W3.0-P0.50-BL-EP; PARTNO W25Q16JVUXIQ; LCSC C2843335
U3: RP2040; QFN-56-1EP_7x7mm_P0.4mm_EP3.2x3.2mm; PARTNO RP2040; LCSC C2040
U4: AP2112K-3.3TRG1; SOT-25-5_L2.9-W1.6-P0.95-LS2.8-BL; PARTNO AP2112K-3.3TRG1; LCSC C51118
Y1: 12MHz; OSC-SMD_4P-L3.2-W2.5-BL; PARTNO X322512MSB4SI; LCSC C9002

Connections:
/1V1: C6.2, C7.2, C8.2, U3.23 (DVDD), U3.45 (VREG_VOUT), U3.50 (DVDD)
/3V3: C5.2, C9.1, C10.2, C11.2, C12.2, C13.2, C14.2, C15.2, C16.2, C18.1, J2.7, R1.1, R7.2, U2.8 (VCC), U3.1 (IOVDD), U3.10 (IOVDD), U3.22 (IOVDD), U3.33 (IOVDD), U3.42 (IOVDD), U3.43 (ADC_AVDD), U3.44 (VREG_IN), U3.48 (USB_VDD), U3.49 (IOVDD), U4.5 (VOUT)
/5V: C17.1, J1.A4B9 (VBUS), J1.B4A9 (VBUS), U1.2 (VDD), U4.1 (VIN), U4.3 (EN)
/A0: J2.5, R27.1
/A1: J2.3, R25.2
/GND: C2.1, C4.1, C5.1, C6.1, C7.1, C8.1, C9.2, C10.1, C11.1, C12.1, C13.1, C14.1, C15.1, C16.1, C17.2, C18.2, J1.A1B12 (GND), J1.B1A12 (GND), J1.S1 (SHIELD), J2.1, J2.2, J2.9, J2.12, R4.1, R5.1, R25.1, R27.2, SW2.2, SW3.2, U1.4 (GND), U2.4 (GND), U2.9 (EPAD), U3.19 (TESTEN), U3.57 (GND), U4.2 (GND), Y1.2, Y1.4
/QSPI_SCLK: U2.6 (CLK), U3.52 (QSPI_SCLK)
/QSPI_SD0: U2.5 (DI(IO0)), U3.53 (QSPI_SD0)
/QSPI_SD1: U2.2 (DO(IO1)), U3.55 (QSPI_SD1)
/QSPI_SD2: U2.3 (/WP(IO2)), U3.54 (QSPI_SD2)
/QSPI_SD3: U2.7 (/HOLDOR/RESET(IO3)), U3.51 (QSPI_SD3)
/QSPI_SS: R1.2, R6.1, U2.1 (/CS), U3.56 (QSPI_SS)
/RST: J2.11, U3.14 (GPIO11)
/RST_DET: J2.10, U3.13 (GPIO10)
/RXD: J2.14, U3.12 (GPIO9)
/SCL: J2.6, U3.18 (GPIO15)
/SDA: J2.4, U3.17 (GPIO14)
/SWCLK: J1.A8 (SBU1), U3.24 (SWCLK)
/SWD: J1.B8 (SBU2), U3.25 (SWD)
/TXD: J2.13, U3.11 (GPIO8)
/USB_DN: J1.A7 (D-), J1.B7 (D-), R3.1
/USB_DP: J1.A6 (D+), J1.B6 (D+), R2.1
/XIN: C4.2, U3.20 (XIN), Y1.3
/XOUT: C2.2, U3.21 (XOUT), Y1.1
unnamed: J1.A5 (CC1), R4.2
unnamed: J1.B5 (CC2), R5.2
unnamed: R6.2, SW2.1
unnamed: U1.1 (DIN), U3.3 (GPIO1)
unnamed: R7.1, SW3.1, U3.26 (RUN)
unnamed: R3.2, U3.46 (USB_DM)
unnamed: R2.2, U3.47 (USB_DP)

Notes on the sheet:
Whatsminer M30S Data Connector
LFG Status LED
RESET
RP2040 Flash
RP2040 Crystal
RP2040 3V3 LDO
BOOT
Universal Serial Bus

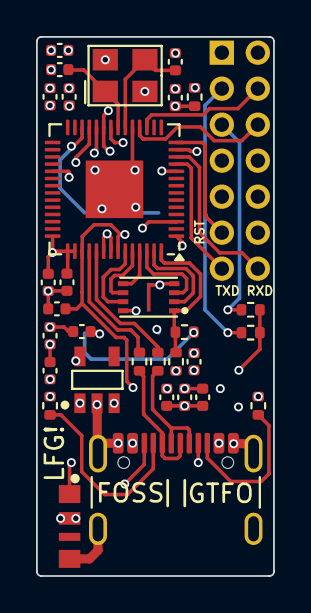
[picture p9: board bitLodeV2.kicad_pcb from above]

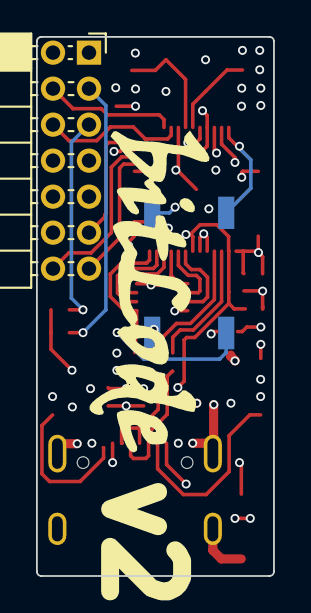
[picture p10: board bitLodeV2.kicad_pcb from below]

Board: 6 copper layers, 13.2 x 30.0 mm, 34 parts (3 on the bottom side), 31 nets.

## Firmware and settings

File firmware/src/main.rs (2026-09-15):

#![no_std]
#![no_main]

use defmt::unwrap;
use defmt_rtt as _;
use panic_probe as _;

use embassy_executor::Spawner;
use embassy_rp::{
    adc::{self},
    bind_interrupts,
    clocks::{ClockConfig, PllConfig},
    flash::{self},
    gpio::{self},
    i2c::{self},
    peripherals::{PIO0, PIO1, USB},
    pio::{self},
    usb::{self},
    Peripheral,
};
use embassy_time::Timer;
use embassy_usb::class::cdc_acm::{CdcAcmClass, State};
use static_cell::StaticCell;

mod control;
mod pio_uart;
mod uart;

pub type I2cPeripheral = embassy_rp::peripherals::I2C1;
pub type I2cDriver = i2c::I2c<'static, I2cPeripheral, i2c::Async>;
pub type UsbPeripheral = embassy_rp::peripherals::USB;
pub type UsbDriver = usb::Driver<'static, UsbPeripheral>;
pub type UsbDevice = embassy_usb::UsbDevice<'static, UsbDriver>;

bind_interrupts!(struct Irqs {
    USBCTRL_IRQ => usb::InterruptHandler<USB>;
    I2C1_IRQ => i2c::InterruptHandler<embassy_rp::peripherals::I2C1>;
    ADC_IRQ_FIFO => embassy_rp::adc::InterruptHandler;
    PIO0_IRQ_0 => embassy_rp::pio::InterruptHandler<PIO0>;
    PIO1_IRQ_0 => embassy_rp::pio::InterruptHandler<PIO1>;
});

const FLASH_SIZE: usize = 4 * 1024 * 1024;

static MANUFACTURER: &str = "256F";
static PRODUCT: &str = "EmberOne00";
/// USB bcdDevice in BCD format: 0xJJMN = version JJ.M.N
/// Major = hardware revision, minor.patch = firmware version.
/// Firmware version restarts at 0.0 with each hardware revision.
const VERSION: u16 = 0x0500;


/// Return a unique serial number for this device by hashing its flash unique ID.
fn serial_number() -> &'static str {
    let p = unsafe { embassy_rp::Peripherals::steal() };
    let flash = unsafe { p.FLASH.clone_unchecked() };
    let mut flash = flash::Flash::<_, flash::Async, FLASH_SIZE>::new(flash, p.DMA_CH0);
    static SERIAL_NUMBER_BUF: StaticCell<[u8; 8]> = StaticCell::new();
    let mut uid = [0u8; 8];
    flash.blocking_unique_id(&mut uid).unwrap();
    let sn = const_murmur3::murmur3_32(&uid, 0);
    let buf = SERIAL_NUMBER_BUF.init([0; 8]);
    hex::encode_to_slice(sn.to_le_bytes(), &mut buf[..]).unwrap();
    unsafe { core::str::from_utf8_unchecked(buf) }
}

#[embassy_executor::main]
async fn main(spawner: Spawner) {
    // 96 MHz sys_clk: 12 MHz xtal × 64 / (4 × 2) = 96 MHz.
    // PIO UART divider = 96 MHz / (8 × 12 MHz) = 1 exactly → zero jitter at 12 Mbaud.
    // Also works for 363,636 baud: 96 MHz / (8 × 363,636) = 33 (error < 0.001%).
    let mut clk_cfg = ClockConfig::crystal(12_000_000);
    if let Some(xosc) = clk_cfg.xosc.as_mut() {
        xosc.sys_pll = Some(PllConfig { refdiv: 1, fbdiv: 64, post_div1: 4, post_div2: 2 });
    }
    let p = embassy_rp::init(embassy_rp::config::Config::new(clk_cfg));

    let mut watchdog = embassy_rp::watchdog::Watchdog::new(p.WATCHDOG);
    watchdog.set_scratch(0, 0);
    watchdog.feed();

    let usb_driver = usb::Driver::new(p.USB, Irqs);

    let usb_config = {
        // VID:PID allocated via https://pid.codes
        let mut config = embassy_usb::Config::new(0xe3be, 0x40e1);
        config.device_release = VERSION;
        config.manufacturer = Some(MANUFACTURER);
        config.product = Some(PRODUCT);
        config.serial_number = Some(serial_number());
        config.max_power = 100;
        config.max_packet_size_0 = 64;
        config.device_class = 0xef;
        config.device_sub_class = 0x02;
        config.device_protocol = 0x01;
        config.composite_with_iads = true;
        config
    };

    let mut builder = {
        static CONFIG_DESCRIPTOR: StaticCell<[u8; 256]> = StaticCell::new();
        static BOS_DESCRIPTOR: StaticCell<[u8; 256]> = StaticCell::new();
        static CONTROL_BUF: StaticCell<[u8; 64]> = StaticCell::new();

        embassy_usb::Builder::new(usb_driver, usb_config, CONFIG_DESCRIPTOR.init([0; 256]), BOS_DESCRIPTOR.init([0; 256]), &mut [], CONTROL_BUF.init([0; 64]))
    };

    let control_class = {
        static STATE: StaticCell<State> = StaticCell::new();
        let state = STATE.init(State::new());
        CdcAcmClass::new(&mut builder, state, 64)
    };

    let asic_uart_class = {
        static STATE: StaticCell<State> = StaticCell::new();
        let state = STATE.init(State::new());
        CdcAcmClass::new(&mut builder, state, 64)
    };

    let asic_uart = {
        let pio::Pio { mut common, sm0, sm1, .. } = pio::Pio::new(p.PIO1, Irqs);
        crate::pio_uart::PioUart::new(115200, &mut common, sm0, sm1, p.PIN_8, p.PIN_9)
    };

    let i2c = {
        let sda = p.PIN_14;
        let scl = p.PIN_15;
        embassy_rp::i2c::I2c::new_async(p.I2C1, scl, sda, Irqs, Default::default())
    };

    let gpio_pins = control::gpio::Pins {
        asic_resetn: gpio::Output::new(p.PIN_11, gpio::Level::High),
        asic_pwr_en: gpio::Output::new(p.PIN_0, gpio::Level::Low),
        asic_io_pwr_en: gpio::Output::new(p.PIN_18, gpio::Level::Low),
    };

    let adc = adc::Adc::new(p.ADC, Irqs, Default::default());
    let adc_pins = control::adc::Pins {
        adc,
        vdd: adc::Channel::new_pin(p.PIN_26, gpio::Pull::None),
        vin: adc::Channel::new_pin(p.PIN_27, gpio::Pull::None),
    };

    let pio::Pio { mut common, sm0, .. } = pio::Pio::new(p.PIO0, Irqs);
    let led = control::led::Led::new(&mut common, sm0, p.PIN_1, p.DMA_CH0.into());

    unwrap!(spawner.spawn(usb_task(builder.build())));
    unwrap!(spawner.spawn(control::usb_task(control_class, i2c, gpio_pins, adc_pins, led)));
    unwrap!(spawner.spawn(uart::usb_task(asic_uart_class, asic_uart)));

    loop {
        watchdog.feed();
        Timer::after_secs(2).await;
    }
}

#[embassy_executor::task]
async fn usb_task(mut usb: UsbDevice) -> ! {
    usb.run().await
}

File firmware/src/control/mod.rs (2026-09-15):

use defmt::info;

use embassy_futures::join::join;
use embassy_rp::usb;
use embassy_sync::{blocking_mutex::raw::ThreadModeRawMutex, channel::Channel};
use embassy_time::{Duration, TimeoutError, Timer};
use embassy_usb::{
    class::cdc_acm::{CdcAcmClass, Receiver, Sender},
    driver::EndpointError,
};
use heapless::Vec;

pub mod i2c;
const I2C_COMMAND: u8 = 5;

pub mod gpio;
const GPIO_COMMAND: u8 = 6;

pub mod adc;
const ADC_COMMAND: u8 = 7;

pub mod led;
const LED_COMMAND: u8 = 8;

pub mod system;
const SYSTEM_COMMAND: u8 = 0x0F;


#[derive(defmt::Format)]
struct Command {
    id: i8,
    bus: u8,
    inner: CommandInner,
}

#[derive(defmt::Format)]
enum CommandInner {
    I2c(i2c::Command),
    Gpio(gpio::Command),
    Adc(adc::Command),
    Led(led::Command),
    System(system::Command),
    Error(CommandError),
}

impl Command {
    fn from_bytes(buf: &[u8]) -> Result<Self, CommandError> {
        let id = buf[0] as i8;
        match buf[2] {
            I2C_COMMAND => Ok(Self {
                id,
                bus: buf[1],
                inner: CommandInner::I2c(i2c::Command::from_bytes(&buf[3..])?),
            }),
            GPIO_COMMAND => Ok(Self {
                id,
                bus: buf[1],
                inner: CommandInner::Gpio(gpio::Command::from_bytes(&buf[3..])?),
            }),
            ADC_COMMAND => Ok(Self {
                id,
                bus: buf[1],
                inner: CommandInner::Adc(adc::Command::from_bytes(&buf[3..])?),
            }),
            LED_COMMAND => Ok(Self {
                id,
                bus: buf[1],
                inner: CommandInner::Led(led::Command::from_bytes(&buf[3..])?),
            }),
            SYSTEM_COMMAND => Ok(Self {
                id,
                bus: buf[1],
                inner: CommandInner::System(system::Command::from_bytes(&buf[3..])?),
            }),
            _ => Err(CommandError::Invalid),
        }
    }
}

#[derive(defmt::Format)]
pub enum CommandError {
    Timeout,               // 0x10
    Invalid,               // 0x11
    BufferOverflow,        // 0x12
    Message(&'static str), // 0xff
}

impl CommandError {
    fn to_bytes(&self) -> Vec<u8, 260> {
        let mut buf = Vec::<u8, 260>::new();
        buf.extend_from_slice(&[0x00, 0x00, 0xff]).unwrap();

        match self {
            CommandError::Timeout => {
                buf.push(0x10).unwrap();
            }
            CommandError::Invalid => {
                buf.push(0x11).unwrap();
            }
            CommandError::BufferOverflow => {
                buf.push(0x12).unwrap();
            }
            CommandError::Message(msg) => {
                buf.push(0xff).unwrap();
                buf.extend_from_slice(msg.as_bytes()).unwrap();
            }
        }

        let len = (buf.len() as u16).to_le_bytes();
        buf[0..2].clone_from_slice(&len);
        buf
    }
}

static COMMAND_CHANNEL: Channel<ThreadModeRawMutex, Command, 8> = Channel::new();

pub struct Controller {
    tx: Sender<'static, super::UsbDriver>,
    i2c: super::I2cDriver,
    gpio: gpio::Pins<'static>,
    adc: adc::Pins<'static>,
    led: led::Led<'static>,
    reboot_to_bootloader: bool,
}

pub trait ControllerCommand {
    async fn handle(&self, controller: &mut Controller) -> Result<Vec<u8, 256>, CommandError>;
}

impl Controller {
    pub async fn run(&mut self) {
        loop {
            let cmd = COMMAND_CHANNEL.receive().await;
            let res = match cmd.inner {
                CommandInner::I2c(cmd) => cmd.handle(self).await,
                CommandInner::Gpio(cmd) => cmd.handle(self).await,
                CommandInner::Adc(cmd) => cmd.handle(self).await,
                CommandInner::Led(cmd) => cmd.handle(self).await,
                CommandInner::System(cmd) => cmd.handle(self).await,
                CommandInner::Error(err) => Err(err),
            };

            let buf = match res {
                Ok(res) => {
                    let mut buf = Vec::<u8, 260>::new();
                    buf.extend_from_slice(&(res.len() as u16).to_le_bytes()).unwrap();
                    buf.push(cmd.id as u8).unwrap();
                    buf.extend_from_slice(&res).unwrap();
                    buf
                }
                Err(err) => {
                    let mut buf = err.to_bytes();
                    buf[2] = cmd.id as u8;
                    buf
                }
            };

            let _ = self.tx.write_packet(&buf).await;

            if self.reboot_to_bootloader {
                // Let the host collect the ack, then enter the ROM USB bootloader (both interfaces enabled).
                info!("Control: rebooting to USB bootloader");
                Timer::after(Duration::from_millis(200)).await;
                embassy_rp::rom_data::reset_to_usb_boot(0, 0);
            }
        }
    }
}

#[embassy_executor::task]
pub async fn usb_task(class: CdcAcmClass<'static, super::UsbDriver>, i2c: super::I2cDriver, gpio: gpio::Pins<'static>, adc: adc::Pins<'static>, led: led::Led<'static>) -> ! {
    let (tx, mut rx, mut _ctrl) = class.split_with_control();
    let mut controller = Controller { tx, i2c, gpio, adc, led, reboot_to_bootloader: false };

    loop {
        rx.wait_connection().await;
        info!("Control: Connected");
        let _ = join(pipe_usb_read(&mut rx), controller.run()).await;
        info!("Control: Disconnected");
    }
}

enum ControlTaskError {
    Disconnected,
}

impl From<EndpointError> for ControlTaskError {
    fn from(val: EndpointError) -> Self {
        match val {
            EndpointError::BufferOverflow => panic!("Buffer overflow"),
            EndpointError::Disabled => ControlTaskError::Disconnected {},
        }
    }
}
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

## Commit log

2025-12-17 First push of bitLoad interface board
    Changes from Aditboard v2
    - move to 7x2mm connector and changed connections appropriately
    - changed logo on bottom silk to bitLode :)
    [aditBoard.kicad_pcb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]
2026-01-18 Fixed the Orientation
    [bitLode-B_Cu.gbr, bitLode-B_Mask.gbr, bitLode-B_Silkscreen.gbr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]
2026-09-15 bitLode V2: fork aditBoard v2, add firmware, tools and diagnostics skill
    - Rename the KiCad project and local libraries to bitLodeV2 with the
    updated schematic, 6-layer PCB, Gerbers, BOM and placement files
    - firmware/: RP2040 Embassy firmware (USB e3be:40e1, PIO UART at 96 MHz,
    SYSTEM control page, per-board serial from flash unique ID) with
    prebuilt ELF/UF2
    - tools/: host-side port discovery, system commands, hashboard init and
    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
    [aditBoard BOM.csv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]
2026-09-15 Update readme with enclosure and AntHat notes
    Added notes about enclosure modification and AntHat equivalent.
